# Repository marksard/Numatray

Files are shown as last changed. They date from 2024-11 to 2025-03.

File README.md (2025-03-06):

# Numatray
The Numatray is a 4-key macropad and fountain pen rest project.

# Completed example

IMGP8970

  

# Layout

  
  

# Support software

QMK Firmware  
https://github.com/marksard/qmk_firmware/tree/own_build/keyboards/marksard/numatray

# Build guide

https://github.com/marksard/Numatray/blob/main/documents/buildguide.md

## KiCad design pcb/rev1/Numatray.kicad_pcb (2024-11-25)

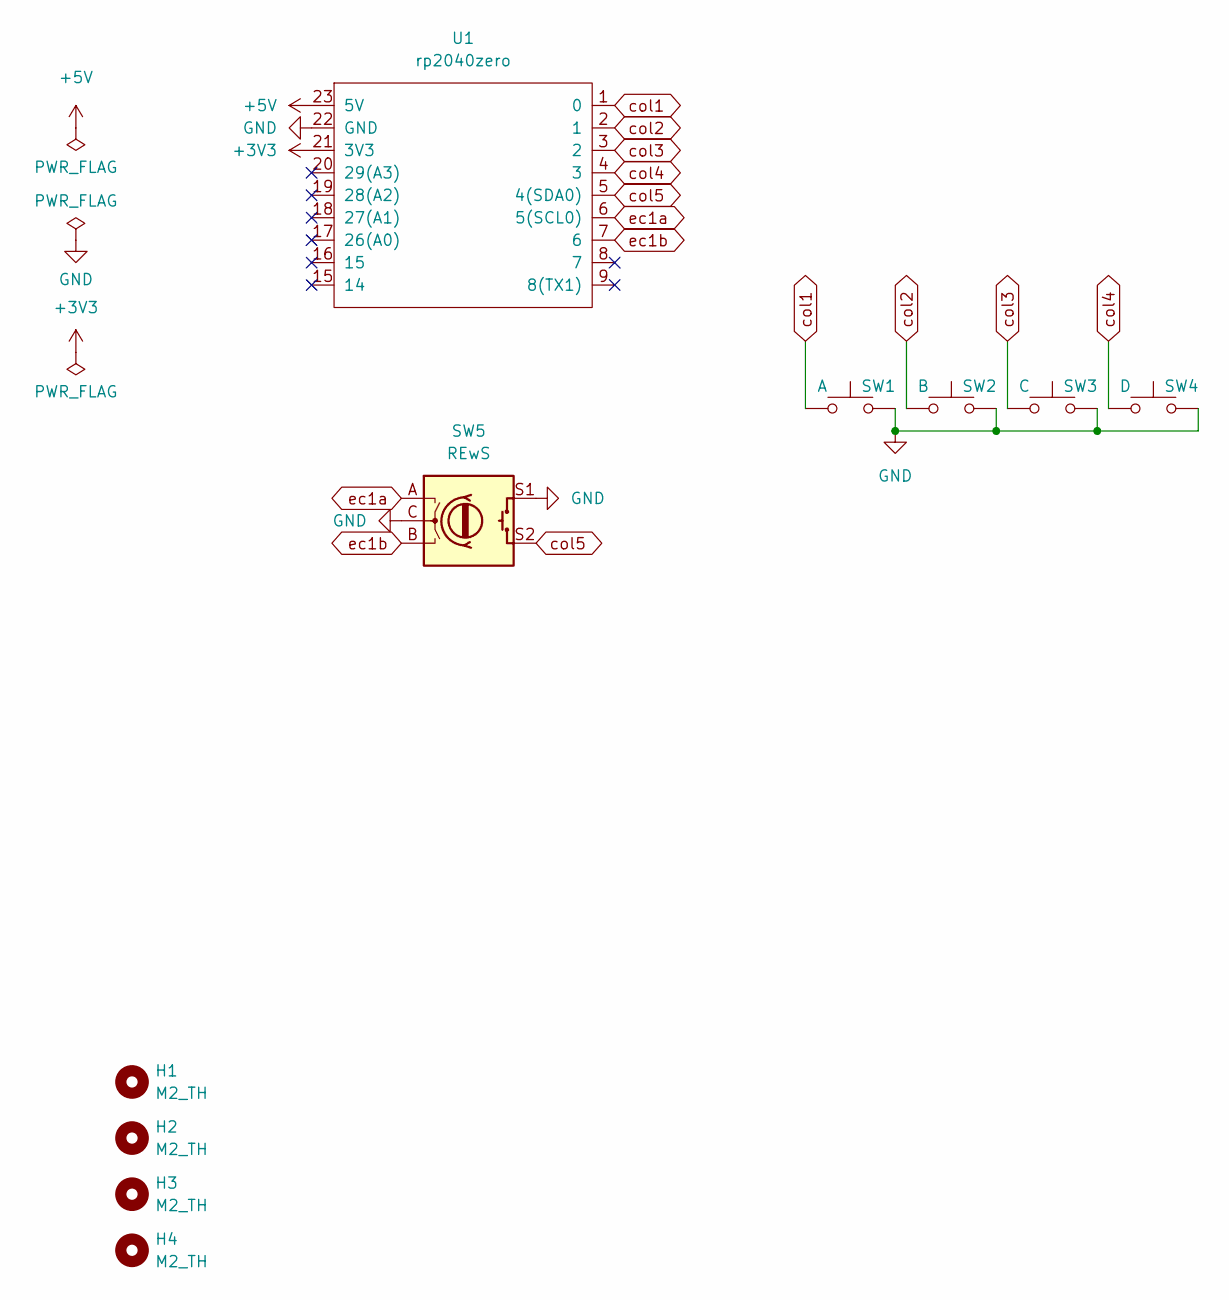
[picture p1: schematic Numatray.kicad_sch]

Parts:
H1, H2, H3, H4: M2_TH; M2_THT_Hole
SW1: A; MX-Solderable-1U; LCSC C5156480
SW2: B; MX-Solderable-1U; LCSC C5156480
SW3: C; MX-Solderable-1U; LCSC C5156480
SW4: D; MX-Solderable-1U; LCSC C5156480
SW5: REwS; RotaryEncoder_EC12E-Switch_Vertical
U1: rp2040zero; rp2040zero_compact

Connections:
+3V3: U1.21 (3V3)
+5V: U1.23 (5V)
GND: SW1.2, SW2.2, SW3.2, SW4.2, SW5.C, SW5.S1, U1.22 (GND)
col1: SW1.1, U1.1 (0)
col2: SW2.1, U1.2 (1)
col3: SW3.1, U1.3 (2)
col4: SW4.1, U1.4 (3)
col5: SW5.S2, U1.5 (4(SDA0))
ec1a: SW5.A, U1.6 (5(SCL0))
ec1b: SW5.B, U1.7 (6)

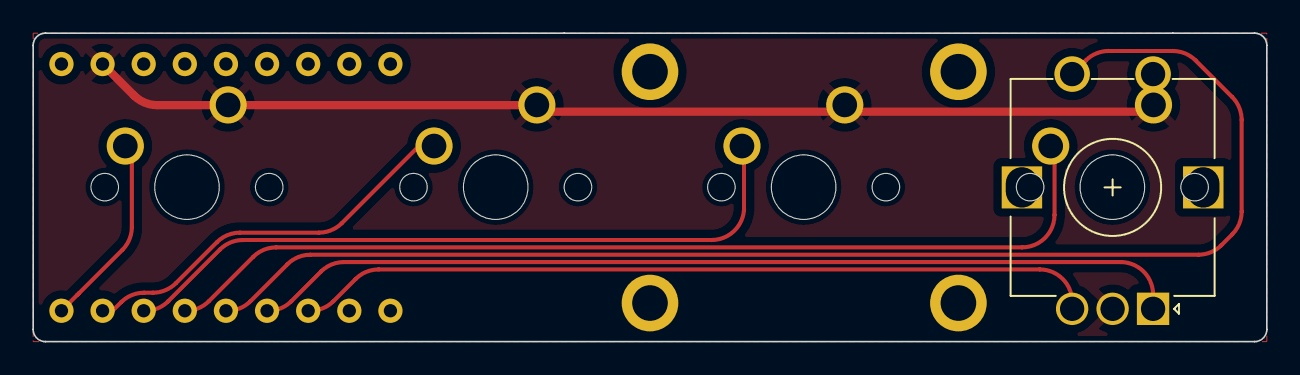
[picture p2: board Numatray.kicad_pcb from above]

Board: 2 copper layers, 76.2 x 19.0 mm, 10 parts (1 on the bottom side), 8 nets.

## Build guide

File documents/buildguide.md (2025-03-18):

# Build guide (ビルドガイド)

20250131_IMGP8951

## The kit includes (キット内容)

|no|name|qty|description|
|:--|:--|:--|:--|
|-|Numatray PCB|1|Macropad PCB|
|-|Numatray Plate|1|FR4 Switch Plate|
|-|Numatray Case|1||
|-|M2 4mm|4||
|-|Rubber Feet|4||
|-|MX Switches|4|As you like|
|-|RP2040 zero|1|（同梱しないキットもあります）|
|-|MAC 8 Conthrough 2.5mm (コンスルー) |2|（同梱しないキットもあります）9pin以上のものが2つ必要です|

## Installation

1. 本体
    1. プレートにスイッチを差し込みます。プレートは細く華奢なため、スイッチをプレートから取り外す場合はスイッチ側のプレートにひっかかっている爪を押し込みながら取ってください。
    1. スイッチのピンが曲がっていないか、向きが間違っていないか注意して、スイッチのピンをPCBに差し込んでください。
    1. スイッチをPCBにはんだ付けしてください。

1. RP2040
    1. MAC 8 Conthrough 2.5mmのピンの向きに注意して、RP2040 zeroと、MAC 8 Conthrough 2.5mmをはんだ付けしてください。リセットボタンとブートボタンの反対側に取り付けてください。（写真参照。同梱していない場合は9pinになるようにカットして取り付けてください）
    1. 本体ユニットにRP2040ユニットを差し込んでください。
    1. PCと接続し、認識されることを確認してください（標準添付のRP2040にはファームウェアは書き込み済みです）

1. 組み立てた基板をケースにビス止めしてください。3Dプリントケースは少し固いですが、ネジを押し込みながら回してください。
1. ラバーの足をケースにとりつけてください。

### photos

コンスルーにはピンの取り付け向きがあります。  
写真の赤枠ようにピンの窓が両方こちらに向くようにしてとりつけてください。
20250131_IMGP8942  

赤枠の各ピンをはんだ付けしてください。  
20250131_IMGP8954

写真のようにスイッチと基板を取り付けてください。スイッチの脚と基板穴の関係上少しキツメに作ってあるのでグッと押し込んでください。  
基板に露出したピンがある赤丸部をはんだづけしてください。  
20250131_IMGP8957

コンスルーをはんだ付けしたRP2040と基板は写真ような方向で取り付けてください。  
基板とコンスルーははんだ付けしなくても良いです。  
20250131_IMGP8944  

EC11/EC10シリーズのロータリーエンコーダーも取り付け可能です
20250131_IMGP8948  

ケースのネジ穴と基板のネジ穴に注意してねじ止めしてください。  
20250131_IMGP8953

---

## Edit the keymap

以下のURLにアクセスし、キーマップを変更出来ます。  

[remap](https://remap-keys.app/)

## Firmware binary file

以下のURLに最新のファームウェアがあります（RP2040 zeroが付属しているものは基本ファームウェアを書き換える必要はありません）  
下記のブートローダーモードの操作を行って、PCにRP2040のフォルダが見えたら、圧縮ファイルから取り出したmarksard_numatray_via.uf2ファイルをコピーしてください。    

[firmware](https://github.com/marksard/qmk_firmware_hex/releases)

## Bootloader Mode

### Method 1 (方法その1)

Connect the keyboard to the PC and operate the tact switch attached to the keyboard in the following order:

1. Hold down the BOOT button and press the RESET button.  
2. Release the RESET button, then release the BOOT button.  

ＰＣにキーボードを接続し、キーボードに取り付けたタクトスイッチを以下の順に操作します。

1. BOOTボタンを押したまま、RESETボタンを押します。
2. RESETボタンを離してから、BOOTボタンを離します。

## If you need help

Twitter: @marksard
Discord: marksard
